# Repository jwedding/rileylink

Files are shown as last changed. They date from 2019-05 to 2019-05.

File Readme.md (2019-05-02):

# RileyLink



A custom designed Bluetooth Smart (BLE) to Sub-1 GHz module. It can be used to bridge any BLE capable smartphone to the world of Sub-1 GHz devices. 

### Setup

 * There is a [FAQ](https://docs.google.com/document/d/1-KlewmRObpUWCTQSq9EPraN8R-6rCksJS_sRSQSexX0/edit#) covering some questions about installing the firmware.
 * [@loudnate](https://github.com/loudnate) recorded a [setup log](https://docs.google.com/document/d/1-bGBXbxVKOs_tDXi68qiOD7bIT6tQlkQydXn5Q-afLc/edit) of his experience.

### Hardware

See the [hardware](https://github.com/ps2/rileylink/tree/master/hardware) directory for design files to build a RileyLink. The hardware design is released under [Creative Commons Share-alike 3.0](http://creativecommons.org/licenses/by-sa/3.0/).  This board has small parts and will need to be reflow soldered; using a solder-paste stencil is recommended. 

RileyLink Hardware

### Order a Pre-Assembed RileyLink
From time-to-time community members do a production run of pre-assembled RileyLink Boards. When they are available you can place an order here [GetRileyLink](https://getrileylink.org/)

### Firmware

The code in the [firmware](https://github.com/ps2/rileylink/tree/master/firmware) directory runs on the RileyLink hardware.  There are two main chips on the RileyLink, and thus two firmware images.

### LED Lights

There are blue and green leds near both chips. The ble113 is on the upper right of the board, and the cc1110 is in the lower middle.  

Blue for the ble113 indicates there are packets received and ready for a phone to pick up. Green means the phone is connected to the ble113.

On the cc1110, I blue is a timer based on/off, letting you know the firmware code is running. Green is toggled when a packet comes in.

The other red LED indicates charging.

### License

The MIT License (MIT)

Copyright (c) 2015 Pete Schwamb

Permission is hereby granted, free of charge, to any person obtaining a copy
of this software and associated documentation files (the "Software"), to deal
in the Software without restriction, including without limitation the rights
to use, copy, modify, merge, publish, distribute, sublicense, and/or sell
copies of the Software, and to permit persons to whom the Software is
furnished to do so, subject to the following conditions:

The above copyright notice and this permission notice shall be included in all
copies or substantial portions of the Software.

THE SOFTWARE IS PROVIDED "AS IS", WITHOUT WARRANTY OF ANY KIND, EXPRESS OR
IMPLIED, INCLUDING BUT NOT LIMITED TO THE WARRANTIES OF MERCHANTABILITY,
FITNESS FOR A PARTICULAR PURPOSE AND NONINFRINGEMENT. IN NO EVENT SHALL THE
AUTHORS OR COPYRIGHT HOLDERS BE LIABLE FOR ANY CLAIM, DAMAGES OR OTHER
LIABILITY, WHETHER IN AN ACTION OF CONTRACT, TORT OR OTHERWISE, ARISING FROM,
OUT OF OR IN CONNECTION WITH THE SOFTWARE OR THE USE OR OTHER DEALINGS IN THE
SOFTWARE.

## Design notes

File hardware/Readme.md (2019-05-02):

# RileyLink Hardware

 * board.sch - circuit schematic
 * board.brd - pcb design file
 * bom.csv - materials list
 * case_bottom.stl - 3d printer model for case bottom
 * case_top.stl - 3d printer model for case top

### Order the PCB from OSH Park:

[RileyLink v1.0](https://oshpark.com/shared_projects/jWrg6WmU)

### Components

The bom.csv file contains a list of parts and quantities along with their Digikey part number.

### PCB Assembly

A stencil for the PCB can be obtained at a reasonable price from [OSH Stencils](https://www.oshstencils.com).  Just upload the .brd file and accept the default mappings.

You will have to look at the schematic and the board design in [Eagle](http://www.cadsoftusa.com/) to know where the parts go, and how they are oriented.

I use a hot-air rework station to flow the solder paste, but you could use a toaster oven setup as well.

Assembled Board

### Case

I created a case using [Tinkercad](https://www.tinkercad.com), a great tool.

3D Printed Case

The case is designed to hold an [850mAh Lipo](https://getrileylink.org/product/850lionbattery/). That battery lasts a day or so when the RileyLink is constant listen mode. It should last longer if the firmware uses a duty cycle that's less than 100%.

### Fitting components inside case

Case Fitting

Note: there’s an issue I have with the case that I haven’t fixed yet; the board in the case can rotate a bit so that the usb port doesn’t line up with the hole. If stick a small something (like those sticky pads that keep cabinet doors from slamming) to the top of the usb port, that fixes the issue.

### 868MHz (EU) version

Since the firmware allows changing of the frequency, and most people are using the 915Mhz antenna successfully with 868Mhz pumps, a custom RileyLink is not needed.

### License

The hardware design is released under [Creative Commons Share-alike 3.0](http://creativecommons.org/licenses/by-sa/3.0/).

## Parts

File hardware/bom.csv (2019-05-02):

Digi-Key Part Number | Quantity 1 | Description | Ref Des
490-3340-1-ND | 2 | 10µF ±10% 6.3V X5R Capacitor 0805 | C4,C11
490-6196-1-ND | 2 | 12pF ±1% 50V C0G, NP0 Capacitor 0402 | C5,C6
311-470LRCT-ND | 4 | 470 ohms 0402 | R7,R11,R12,R13
609-3695-1-ND | 2 | CC-Debugger Header | CC1110-DEBUG,BLE113-DEBUG
LM3671MF-3.3/NOPBCT-ND | 1 | 3.3V Buck Converter 0.6A SOT23 | VREG
445-7482-1-ND | 3 | 4.7µF ±10% 10V X5R Capacitor 0603 | C2,C3,C14
587-1227-1-ND | 6 | 0.10µF ±10% 10V X5R Capacitor 0402 | C1,C7,C8,C10,C12,C13
455-1749-1-ND | 1 | 2 Positions JST Header 2mm | JP1
490-5344-1-ND | 1 | 2.2µH Shielded Wirewound Inductor 1.46A | L1
MCP73831T-2DCI/OTCT-ND | 1 | L-ION Battery Management IC | U1
296-38560-1-ND | 1 | CC1110 SOC RF Transceiver | CC1110
644-1052-1-ND | 1 | 24MHz ±15ppm Crystal 8pF 50 Ohm | X1
490-1320-1-ND | 1 | 1µF ±10% 6.3V X5R Capacitor 0402 | C9
ANT-916-JJB-RA-ND | 1 | Antenna 916MHZ | ANT
401-2016-1-ND | 1 | SWITCH SLIDE SPDT 300MA 6V | PWR
1446-1035-1-ND | 1 | Bluetooth Low Energy BLE113-A 256K | U3
311-0.0JRCT-ND | 1 | 0 Ohm Jumper | R9
511-1299-1-ND | 2 | LED GREEN CLEAR 0603 SMD | LED3,LED4
311-2.0KJRCT-ND | 1 | 2k Ohm ±5% 0.063W, 1/16W Resistor 0402 | R1
311-56.0KLRCT-ND | 1 | 56k Ohm ±1% 0.063W, 1/16W Resistor 0402 | R3
H2959CT-ND | 1 | USB - mini B USB 2.0 Receptacle Connector | X3
311-330JRCT-ND | 1 | 330 Ohm ±5% 0.063W, 1/16W Resistor 0402 | R2
160-1447-1-ND | 1 | LED RED CLEAR 0603 SMD | LED1
LNJ937W8CRACT-ND | 2 | LED BLUE 0603 SMD | LED2,LED5
712-1541-1-ND | 1 | 915 MHz Impedance Matched Balun-Filter | IC1
 | 40

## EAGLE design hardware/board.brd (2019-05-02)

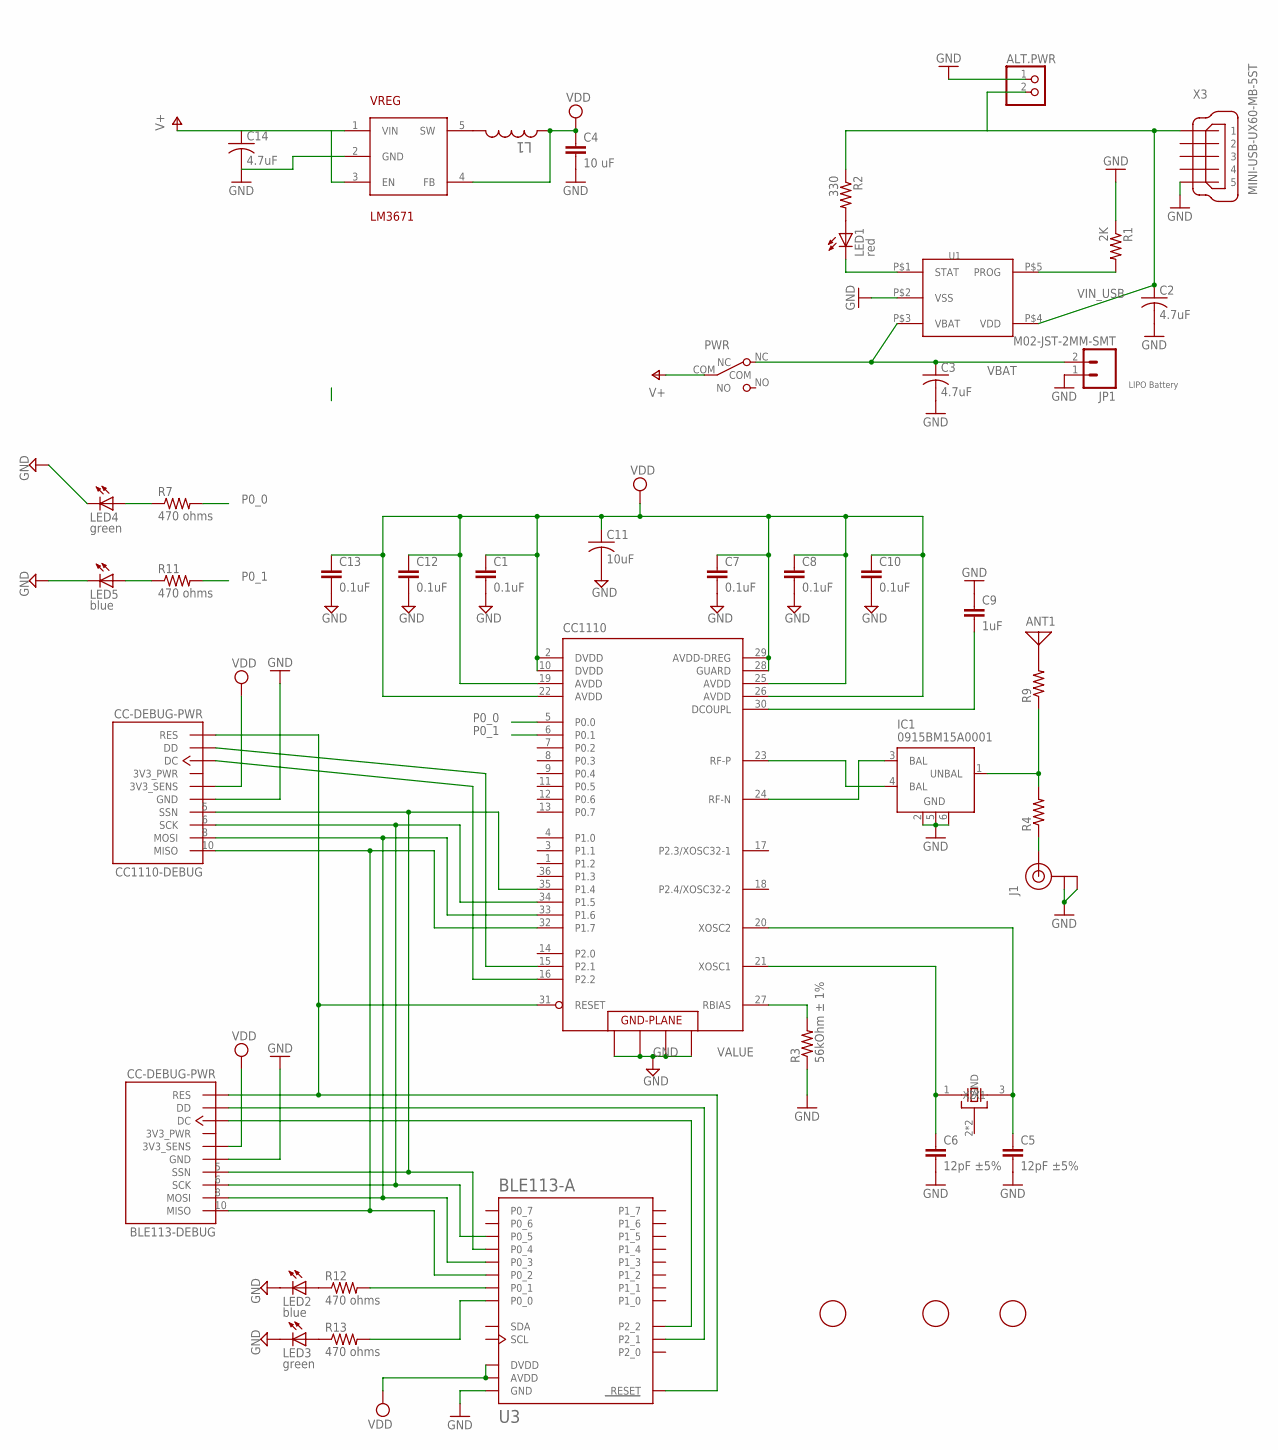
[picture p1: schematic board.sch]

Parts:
ALT.PWR: PINHD-1X2; 1X02
ANT1: ANTENNA; PAD-01
BLE113-DEBUG: CC-DEBUG-PWR; CC-P05
C1, C7, C8, C10, C12, C13: 0.1uF; C0402
C2, C3, C14: 4.7uF; C0603K
C4: 10 uF; C0805K
C5, C6: 12pF ±5%; C0402K
C9: 1uF; C0402K
C11: 10uF; C0805K
CC1110: CC1110; QLP-36_UPDATE
CC1110-DEBUG: CC-DEBUG-PWR; CC-P05
FID1, FID2, FID3: FIDUCIAL; FIDUCIAL_1MM
IC1: 0915BM15A0001
J1: U.FL
JP1: M02-JST-2MM-SMT; JST-2-SMD
L1: 2.2 uH; L2825P
LED1: red; SML0603
LED2, LED5: blue; SML0603
LED3, LED4: green; SML0603
PWR: SW_SLIDE; SLIDE_SWITCH_SMD
R1: 2K; R0402
R2: 330; R0402
R3: 56kOhm ± 1%; R0402
R4, R9: R-US_R0402; R0402
R7, R11, R12, R13: 470 ohms; R0402
U1: MCP73831; 5PIN_SOT23
U3: BLE113-A
VREG: LM3671; SOT23-5
X1: 24MHz 8pF 10ppm -20C +70C; CTS_32X25
X3: MINI-USB-UX60-MB-5ST; UX60-MB-5ST

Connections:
DC: CC1110.16 (P2.2), CC1110-DEBUG.3 (DC)
DC_BLE: BLE113-DEBUG.3 (DC), U3.P2_2
DD: CC1110.15 (P2.1), CC1110-DEBUG.4 (DD)
DD_BLE: BLE113-DEBUG.4 (DD), U3.P2_1
GND: ALT.PWR.1, BLE113-DEBUG.1 (GND), C1.2, C2.2, C3.2, C4.2, C5.2, C6.2, C7.2, C8.2, C9.1, C10.2, C11.2, C12.2, C13.2, C14.2, CC1110.37 (GND), CC1110.38 (GND), CC1110.39 (GND), CC1110.40 (GND), CC1110-DEBUG.1 (GND), IC1.2 (GND), IC1.5 (GND), IC1.6 (GND), J1.P$1 (GND), J1.P$2 (GND), JP1.1 (2), LED2.C, LED3.C, LED4.C, LED5.C, R1.1, R3.1, U1.P$2 (VSS), U3.GND, U3.GND@2 (GND), U3.GND@3 (GND), U3.GND@4 (GND), U3.GND@5 (GND), U3.GND@6 (GND), U3.GND@7 (GND), U3.GND@8 (GND), U3.GND@9 (GND), U3.GND@10 (GND), VREG.2 (GND), X1.2 (GND), X1.4 (GND), X3.5
MISO: BLE113-DEBUG.10 (MISO), CC1110.32 (P1.7), CC1110-DEBUG.10 (MISO), U3.P0_2
MOSI: BLE113-DEBUG.8 (MOSI), CC1110.33 (P1.6), CC1110-DEBUG.8 (MOSI), U3.P0_3
unnamed: LED1.C, U1.P$1 (STAT)
unnamed: R1.2, U1.P$5 (PROG)
unnamed: LED1.A, R2.2
unnamed: CC1110.24 (RF-N), IC1.3 (BAL)
unnamed: CC1110.23 (RF-P), IC1.4 (BAL)
unnamed: J1.P$3 (SIGNAL), R4.1
unnamed: IC1.1 (UNBAL), R4.2, R9.1
unnamed: ANT1.1, R9.2
unnamed: CC1110.27 (RBIAS), R3.2
unnamed: L1.2, VREG.5 (SW)
unnamed: C9.2, CC1110.30 (DCOUPL)
unnamed: C6.1, CC1110.21 (XOSC1), X1.1 (X1)
unnamed: C5.1, CC1110.20 (XOSC2), X1.3 (X2)
unnamed: LED4.A, R7.1
unnamed: LED5.A, R11.1
unnamed: LED2.A, R12.1
unnamed: LED3.A, R13.1
unnamed: R12.2, U3.P0_1
unnamed: R13.2, U3.P0_0
P0_0: CC1110.5 (P0.0), R7.2
P0_1: CC1110.6 (P0.1), R11.2
RESET: BLE113-DEBUG.7 (RES), CC1110.31 (RESET), CC1110-DEBUG.7 (RES), U3.RESET
SCK: BLE113-DEBUG.6 (SCK), CC1110.34 (P1.5), CC1110-DEBUG.6 (SCK), U3.P0_5
SSN: BLE113-DEBUG.5 (SSN), CC1110.35 (P1.4), CC1110-DEBUG.5 (SSN), U3.P0_4
V+: C14.1, PWR.COM, VREG.1 (VIN), VREG.3 (EN)
VBAT: C3.1, JP1.2 (1), PWR.NC, U1.P$3 (VBAT)
VDD: BLE113-DEBUG.2 (3V3_SENS), C1.1, C4.1, C7.1, C8.1, C10.1, C11.1, C12.1, C13.1, CC1110.2 (DVDD), CC1110.10 (DVDD), CC1110.19 (AVDD), CC1110.22 (AVDD), CC1110.25 (AVDD), CC1110.26 (AVDD), CC1110.28 (GUARD), CC1110.29 (AVDD-DREG), CC1110-DEBUG.2 (3V3_SENS), L1.1, U3.AVDD, U3.DVDD, VREG.4 (FB)
VIN_USB: ALT.PWR.2, C2.1, R2.1, U1.P$4 (VDD), X3.1

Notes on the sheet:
LIPO Battery

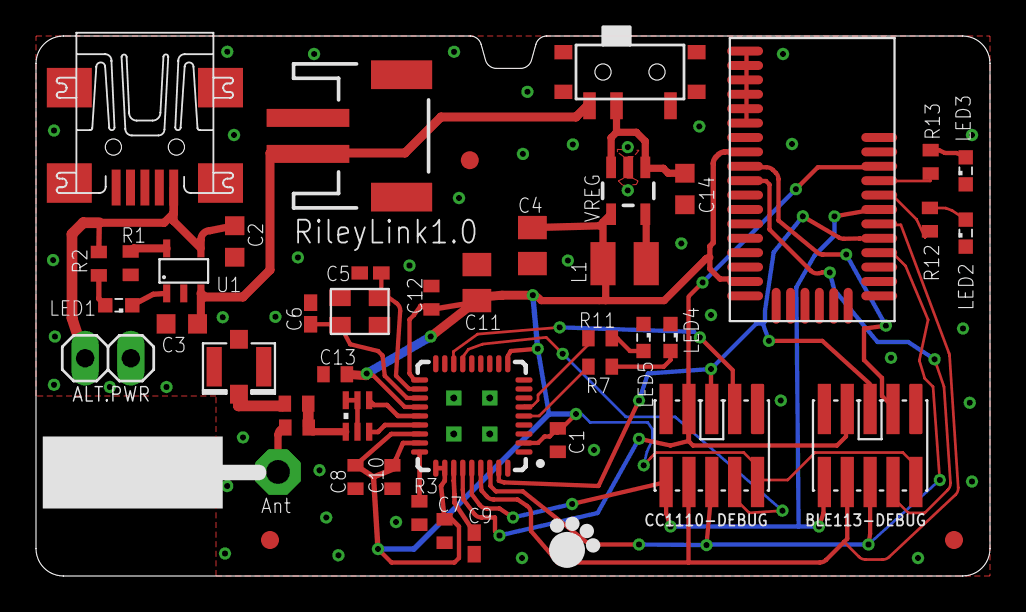
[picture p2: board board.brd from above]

Board: 2 copper layers, 53.0 x 30.0 mm, 46 parts (0 on the bottom side), 35 nets.

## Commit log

2015-08-22 Use blue led
2016-04-22 Experiment: fix antenna test point
    [board.brd, board.sch]
2016-11-21 Fix bad trace under supply cap
    [board.brd]

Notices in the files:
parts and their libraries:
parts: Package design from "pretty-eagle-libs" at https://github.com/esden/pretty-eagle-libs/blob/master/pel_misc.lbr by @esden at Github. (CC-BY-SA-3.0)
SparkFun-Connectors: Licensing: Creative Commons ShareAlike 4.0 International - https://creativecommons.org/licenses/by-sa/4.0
